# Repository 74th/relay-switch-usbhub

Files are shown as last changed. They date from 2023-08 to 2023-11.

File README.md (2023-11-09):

# Relay Switch USB 2.0 Hub

This is a USB hub with USB switching function using relays.

Many existing USB hubs with USB host switching function only allow 2-port switching, and I made this kit because we wanted a 4-port hub.
Since there are no USB hubs using USB Type-C available on the market, it is convenient to use USB Type-C.
Since I wanted to place the USB hub behind the display, we also added the ability to switch remotely using a Grove cable.

Usually a dedicated USB switching IC should be used for USB switching, but this is achieved by using a relay to switch between DM/DP. It works by me, so I am not guaranteeing that it works, but I am publishing it.

リレーを使った USB 切り替え機能付き USB ハブです。

既存の USB ホスト切り替え機能付き USB ハブでは、多くが 2 ポートしか切り替えられず、4 ポートが欲しかったため作りました。
USB Type-C を使った USB ハブは販売されていないため、USB Type-C が使えると便利です。
USB ハブはディスプレイの裏に置きたかったため、Grove ケーブルを使ってリモートから切り替えられる機能もつけました。

本来は USB 切り替えには USB 切り替え専用の IC を使うべきですが、これはリレーを使って DM/DP を切り替えることで実現しています。私の所では動作しているので、動作は保証しませんが、公開しています。

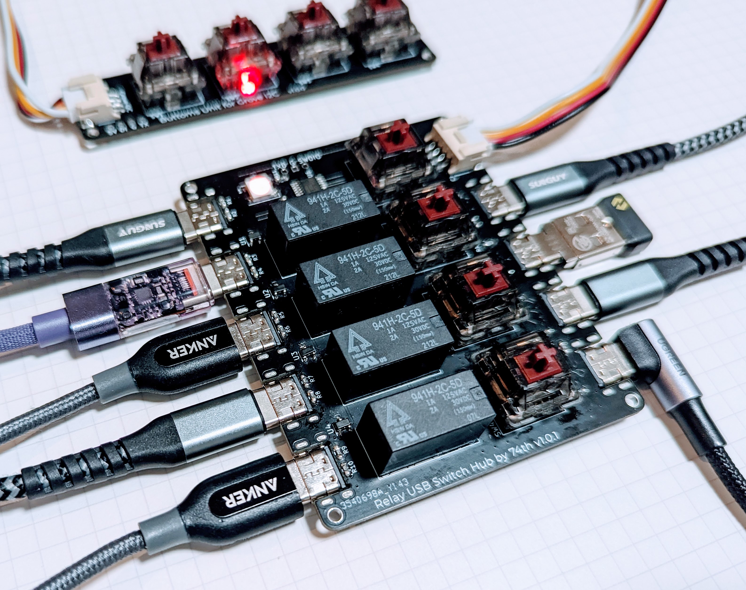
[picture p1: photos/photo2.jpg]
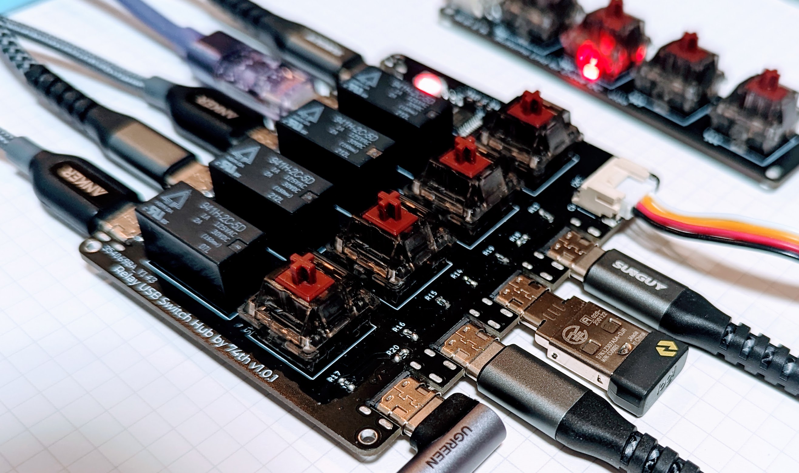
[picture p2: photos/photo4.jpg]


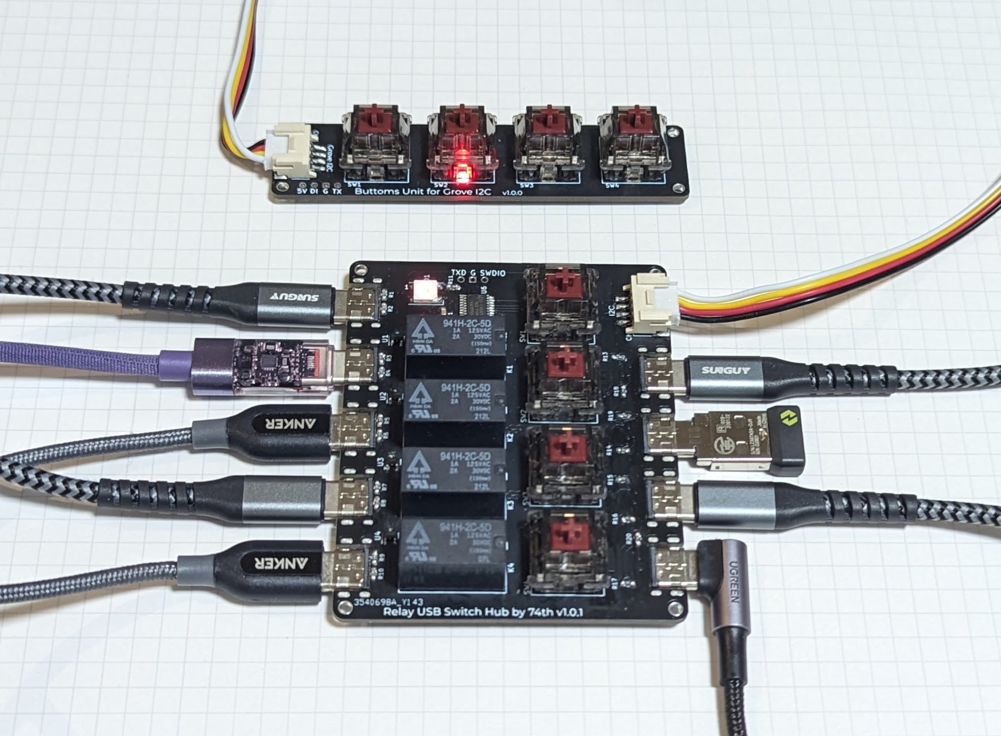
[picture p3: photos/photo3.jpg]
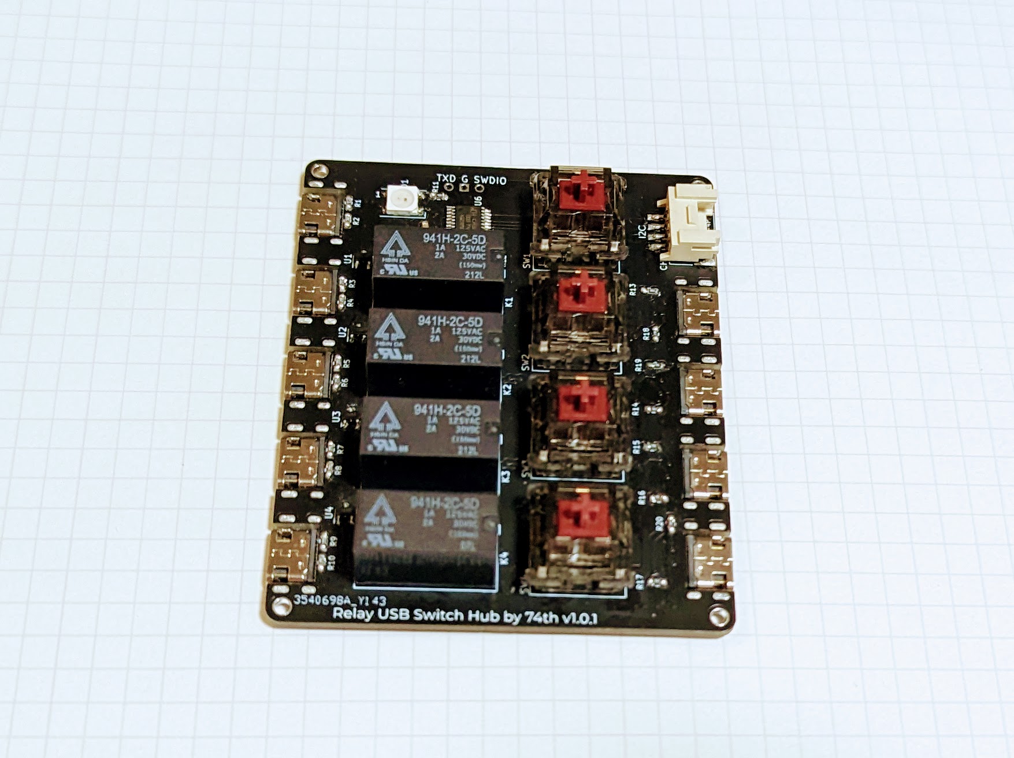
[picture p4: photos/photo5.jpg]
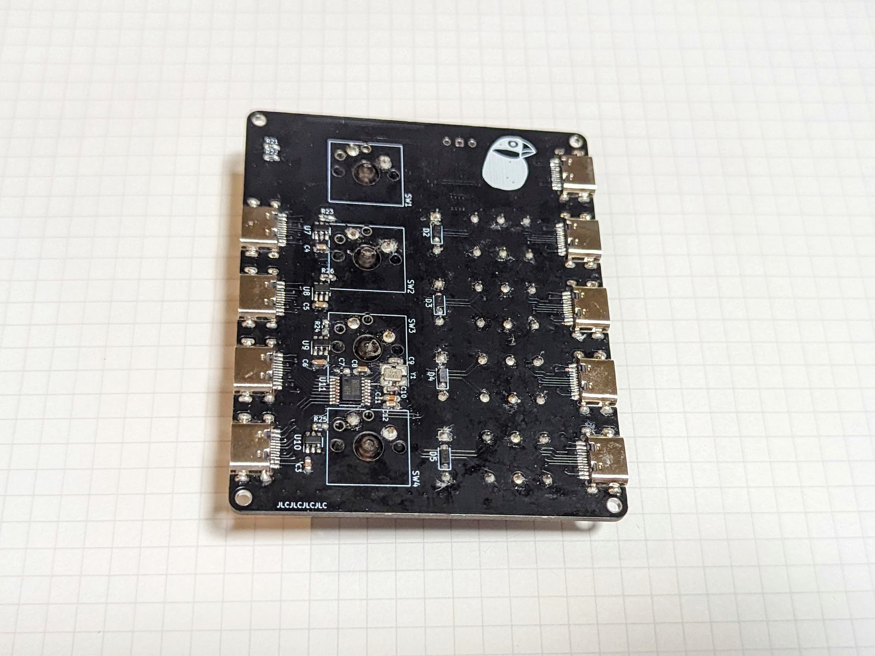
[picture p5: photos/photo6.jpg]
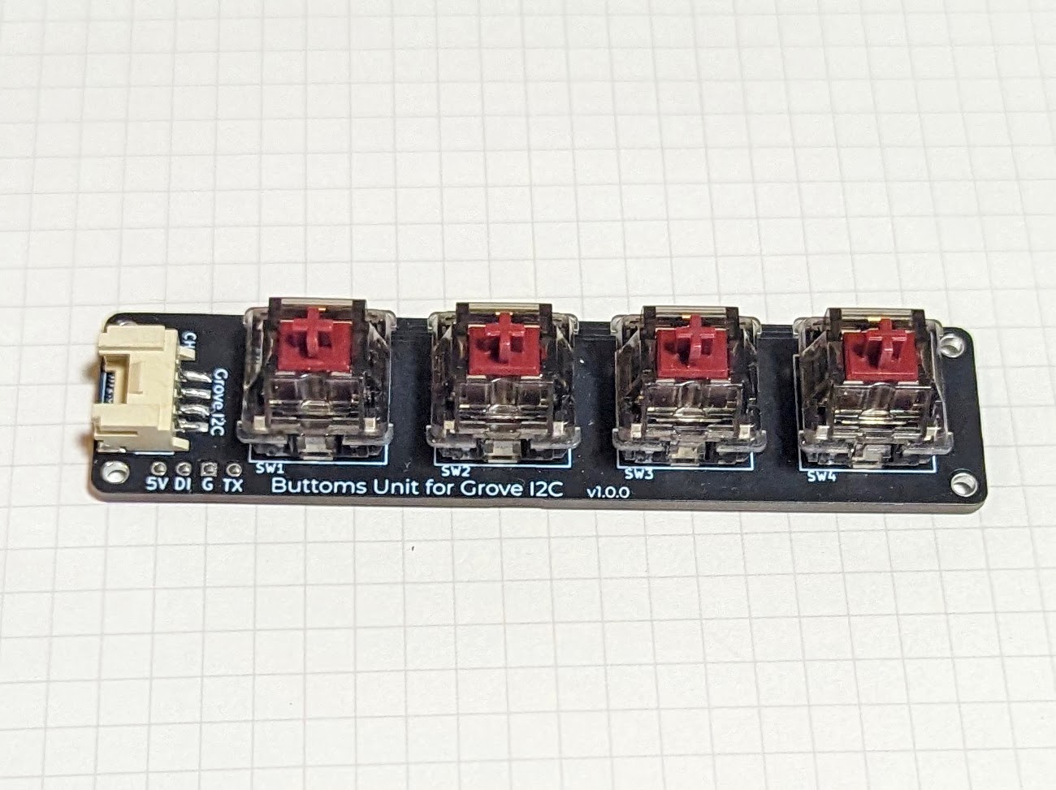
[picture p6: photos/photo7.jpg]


> Shop [BOOTH](https://74th.booth.pm/items/5080690)

## features

- Switch between 4 USB Hosts with Relay
- 4-port USB 2.0 hub using CH334
- MX compatible DIY keyboard switches can be used to switch between USB hosts
- Currently enabled USB host is indicated by LED color
- A Grove cable can be used to place a USB host switching switch at a remote location
- Power protection IC on both USB device and USB host side
- USB port next to LED for power supply
- All USB ports are Type-C

### Japanese

- リレーを使った USB ホスト切り替え機能
- CH334 を使った 4 ポート USB 2.0 ハブ
- USB ホストの切り替えスイッチには MX 互換自作キーボードスイッチが使える
- 現在有効な USB ホストを LED の色で表示する
- Grove ケーブルで、離れた位置に USB ホストを切り替えるスイッチを置くことができる
- USB デバイス、USB ホスト側の両方に電源保護 IC を搭載
- LED 横の USB ポートは電源供給用
- 全ての USB ポートは Type-C

## Repository Structure

- Relay USB Hub
  - PCB KiCad Data: [./main-pcb](./main-pcb)
  - Relay Control MCU Firmware(CH32V003F6P6): [./main-firmware](./main-firmware)
  - Case 3D Printer Model(WIP): [./case/case-bottom.stl](./case/case-bottom.stl)
- Button Unit Grove I2C
  - PCB KiCad Data: [./remote_switch-pcb](./remote_switch-pcb)
  - Button Unit MCU Firmware(CH32V003F6P6): [./remote_switch-firmware](./remote_switch-firmware)
  - Case 3D Printer Model(WIP): [./case/remote-bottom.stl](./case/remote-bottom.stl)

## About Using IC

- CH334R: USB 2.0 Hub controller IC
  - Product Site: https://www.wch-ic.com/products/CH334.html
  - Datasheet: https://www.wch-ic.com/downloads/CH334DS0_PDF.html
- CH32V003: Low Cost General Purpose MCU
  - Product Site: https://www.wch-ic.com/products/CH32V003.html
  - Datasheet: https://www.wch-ic.com/downloads/CH32V003DS0_PDF.html

## Relay USB Hub v1.0.1

- Semantics: [PDF](./main-pcb/relay_usb_switch_hub-v1.0.1-semantics.pdf) [Kicanvas](https://kicanvas.org/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)
- PCB: [Kicanvas](https://kicanvas.org/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)

### BOM

| Reference | Name | Quantity |
| --- | --- | --- |
| C1, C3-C6, C8, C12 | Capacitor 0603 10uF | 7 |
| C2, C11 | Capacitor 0603 100nF | 2 |
| C7 | NC | 1 |
| C9, C10 | Capacitor 0603 20-22pF | 2 |
| CH2 | HY2.0 Socket SMD 4Pin - I2C | 1 |
| D1 | RGBLED WS2812B | 1 |
| D2-D5 | Fast Switching Diode SOD-123 1N4148W | 4 |
| J1-J4 | USB Type-C Receptacle - USB Device | 4 |
| J5 | USB Type-C Receptacle - Power | 1 |
| J6-J9 | USB Type-C Receptacle - Com Host | 4 |
| K1-K4 | 5V 2 Form C Relay | 4 |
| R1-R10 | Register 0603 5.1kΩ | 10 |
| R11 | Register 0603 27Ω | 1 |
| R12 | Register 0603 10kΩ | 1 |
| R13-R20, R23-R26 | Register 0603 56kΩ | 12 |
| R21, R22 | Register 0603 1kΩ | 2 |
| SW1-SW4 | Cherry MX Compatible Switch or Kailh Choc Switch | 4 |
| U1-U4 | USB Power Protection IC SOT-23 CH213K | 4 |
| U6 | MCU LQFP48 WCH CH32V003F4P6 | 1 |
| U7-U10 | USB Power Protection IC SOT-23-6L CH217K | 4 |
| U11 | USB 2.0 Hub Controller QSOP-16 CH334R | 1 |
| Y1 | Crystal 3225 12MHz | 1 |

## Button Unit Grove v1.0.0

- Semantics: [PDF](./remote_switch-pcb/button_unit_grove_i2c-v1.0.0-semantics.pdf) [Kicanvas](https://kicanvas.org/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)
- PCB: [Kicanvas](https://kicanvas.org/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)

### BOM

| Reference | Name | Quantity |
| --- | --- | --- |
| C1 | Capacitor 0805 100nF | 1 |
| C2 | Capacitor 0805 10uF | 1 |
| CH1 | HY2.0 Socket SMD 4Pin - Grove I2C | 1 |
| D1-D4 | RGBLED 3528 SK6812MINI-E | 4 |
| R1 | Register 0805 10kΩ | 1 |
| R2 | Register 0805 27Ω | 1 |
| SW1-SW4 | Cherry MX Compatible Switch or Kailh Choc Switch | 4 |
| U1 | MCU LQFP48 WCH CH32V003F4P6 | 1 |

## License

MIT

日本では販売しないでいただけるとありがたいです。

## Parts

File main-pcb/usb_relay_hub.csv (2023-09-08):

Reference | Value | Footprint | Sim.Device | Sim.Pins | 数量
C1, C3-C6, C8, C12 | 10u | $74th:Capacitor_0603_1608 |  |  | 7
C2, C11 | 100n | $74th:Capacitor_0603_1608 |  |  | 2
C9, C10 | 22p | $74th:Capacitor_0603_1608 |  |  | 2
CH1 | Dubug | $74th:CH32V003-DebugPort |  |  | 1
CH2 | I2C | $74th:HY2.0_Socket_SMD_4Pin |  |  | 1
D1 | WS2812B | LED_SMD:LED_WS2812B_PLCC4_5.0x5.0mm_P3.2mm |  |  | 1
D2-D5 | 1N4148W | $74th:D_SOD-123 | D | 1=K 2=A | 4
J1-J4 | USB2.0_C_v3-R | $74th:USB-C-12-Pin-MidMount-ali-v5 |  |  | 4
J5 | Power | $74th:USB-C-12-Pin-MidMount-ali-v5 |  |  | 1
J6-J9 | Com | $74th:USB-C-12-Pin-MidMount-ali-v5 |  |  | 4
K1-K4 | 941H-2C-5D | Relay_THT:Relay_DPDT_Finder_30.22 |  |  | 4
R1-R10 | 5.1k | $74th:Register_0603_1608 |  |  | 10
R11 | 27 | $74th:Register_0603_1608 |  |  | 1
R12 | 10k | $74th:Register_0603_1608 |  |  | 1
R13-R20, R23-R26 | 56k | $74th:Register_0603_1608 |  |  | 12
R21, R22 | 1k | $74th:Register_0603_1608 |  |  | 2
SW1-SW4 | SW_Push | $sparrow62:MXChocDirect_1Side_1.0u |  |  | 4
U1-U4 | CH213K | Package_TO_SOT_SMD:SOT-23 |  |  | 4
U6 | CH32V003F4P6 | Package_SO:TSSOP-20_4.4x6.5mm_P0.65mm |  |  | 1
U7-U10 | CH217K | Package_TO_SOT_SMD:SOT-23-6 |  |  | 4
U11 | CH334R | Package_SO:QSOP-16_3.9x4.9mm_P0.635mm |  |  | 1
Y1 | 12M | $74th:Crystal_SMD_3225-4Pin_3.2x2.5mm_HandSoldering |  |  | 1

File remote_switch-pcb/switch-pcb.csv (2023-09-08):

Reference | Value | Footprint | 数量
C1 | 100n | $74th:Capacitor_0805_2012 | 1
C2 | 10u | $74th:Capacitor_0805_2012 | 1
CH1 | Grove I2C | $74th:HY2.0_Socket_SMD_4Pin | 1
CH2 | SWD 1Wire & UART TX | $74th:CH32V003-DebugPort_with_vcc | 1
D1-D4 | SK6812MINI | $74th:YS-SK6812MINI-E-BACK-RIGHT | 4
R1 | 10k | $74th:Register_0805_2012 | 1
R2 | 27 | $74th:Register_0805_2012 | 1
SW1-SW4 | SW_Push | $sparrow62:MXChocDirect_1Side_1.0u | 4
U1 | CH32V003F4P6 | Package_SO:TSSOP-20_4.4x6.5mm_P0.65mm | 1

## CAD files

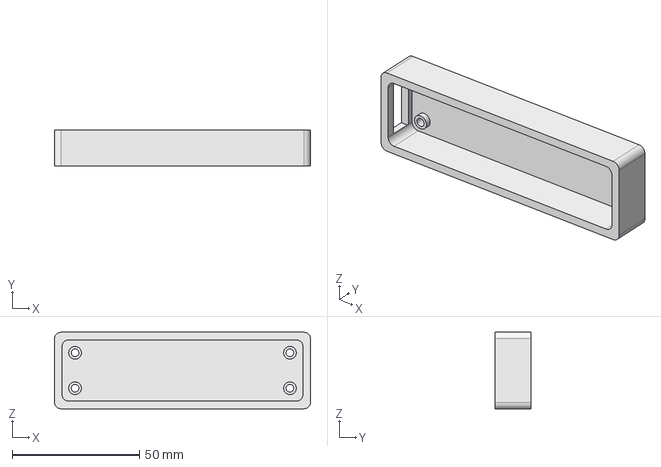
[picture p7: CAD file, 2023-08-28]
case/releay-switch-usbhub-remote.FCStd
100.6 x 14.0 x 30.1 mm

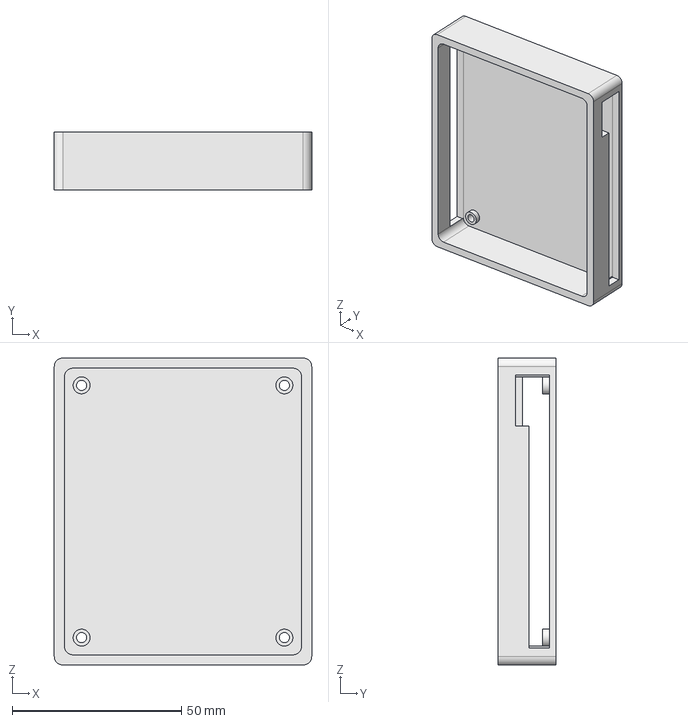
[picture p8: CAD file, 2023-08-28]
case/relay-switch-usbhub-bottom.FCStd
76.0 x 17.2 x 90.6 mm

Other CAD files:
case/remote-bottom.stl
case/case-bottom.stl

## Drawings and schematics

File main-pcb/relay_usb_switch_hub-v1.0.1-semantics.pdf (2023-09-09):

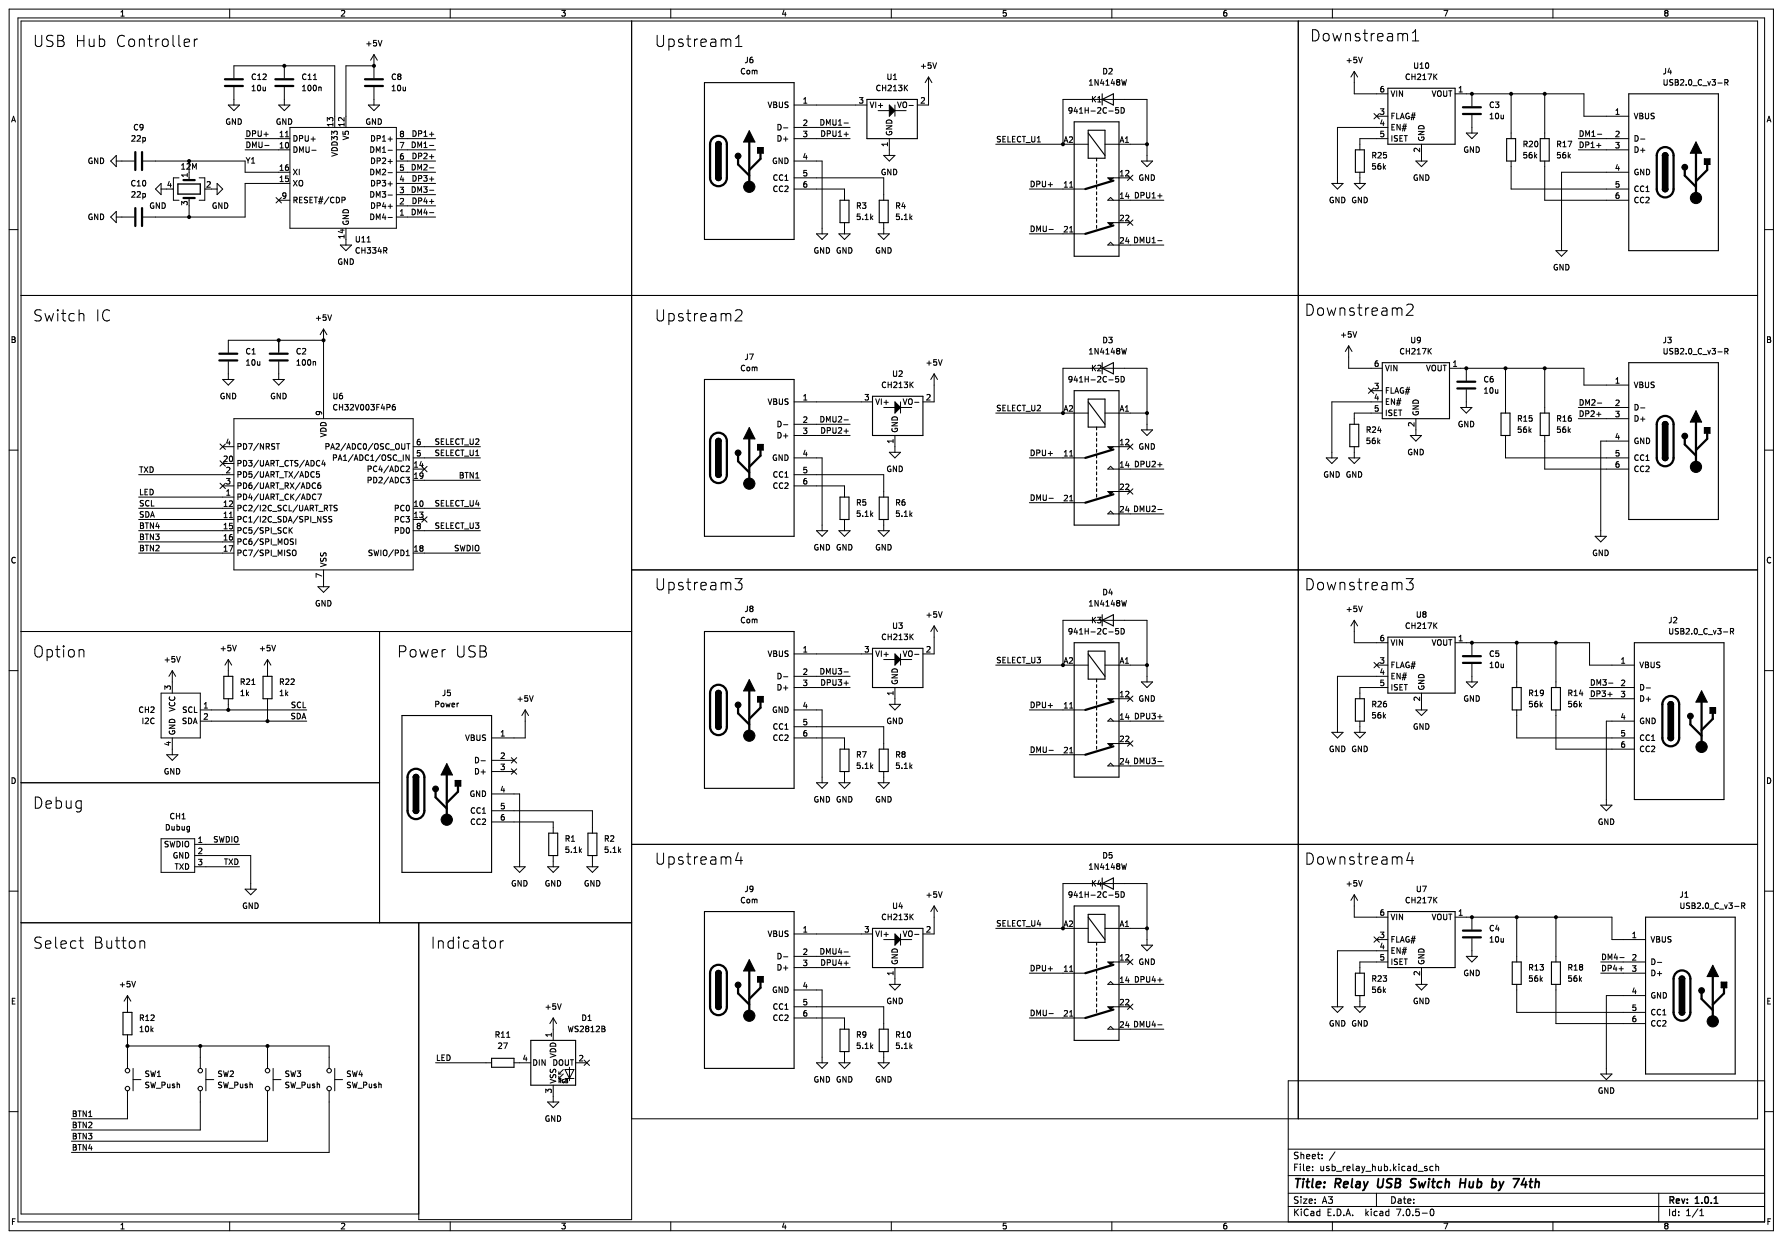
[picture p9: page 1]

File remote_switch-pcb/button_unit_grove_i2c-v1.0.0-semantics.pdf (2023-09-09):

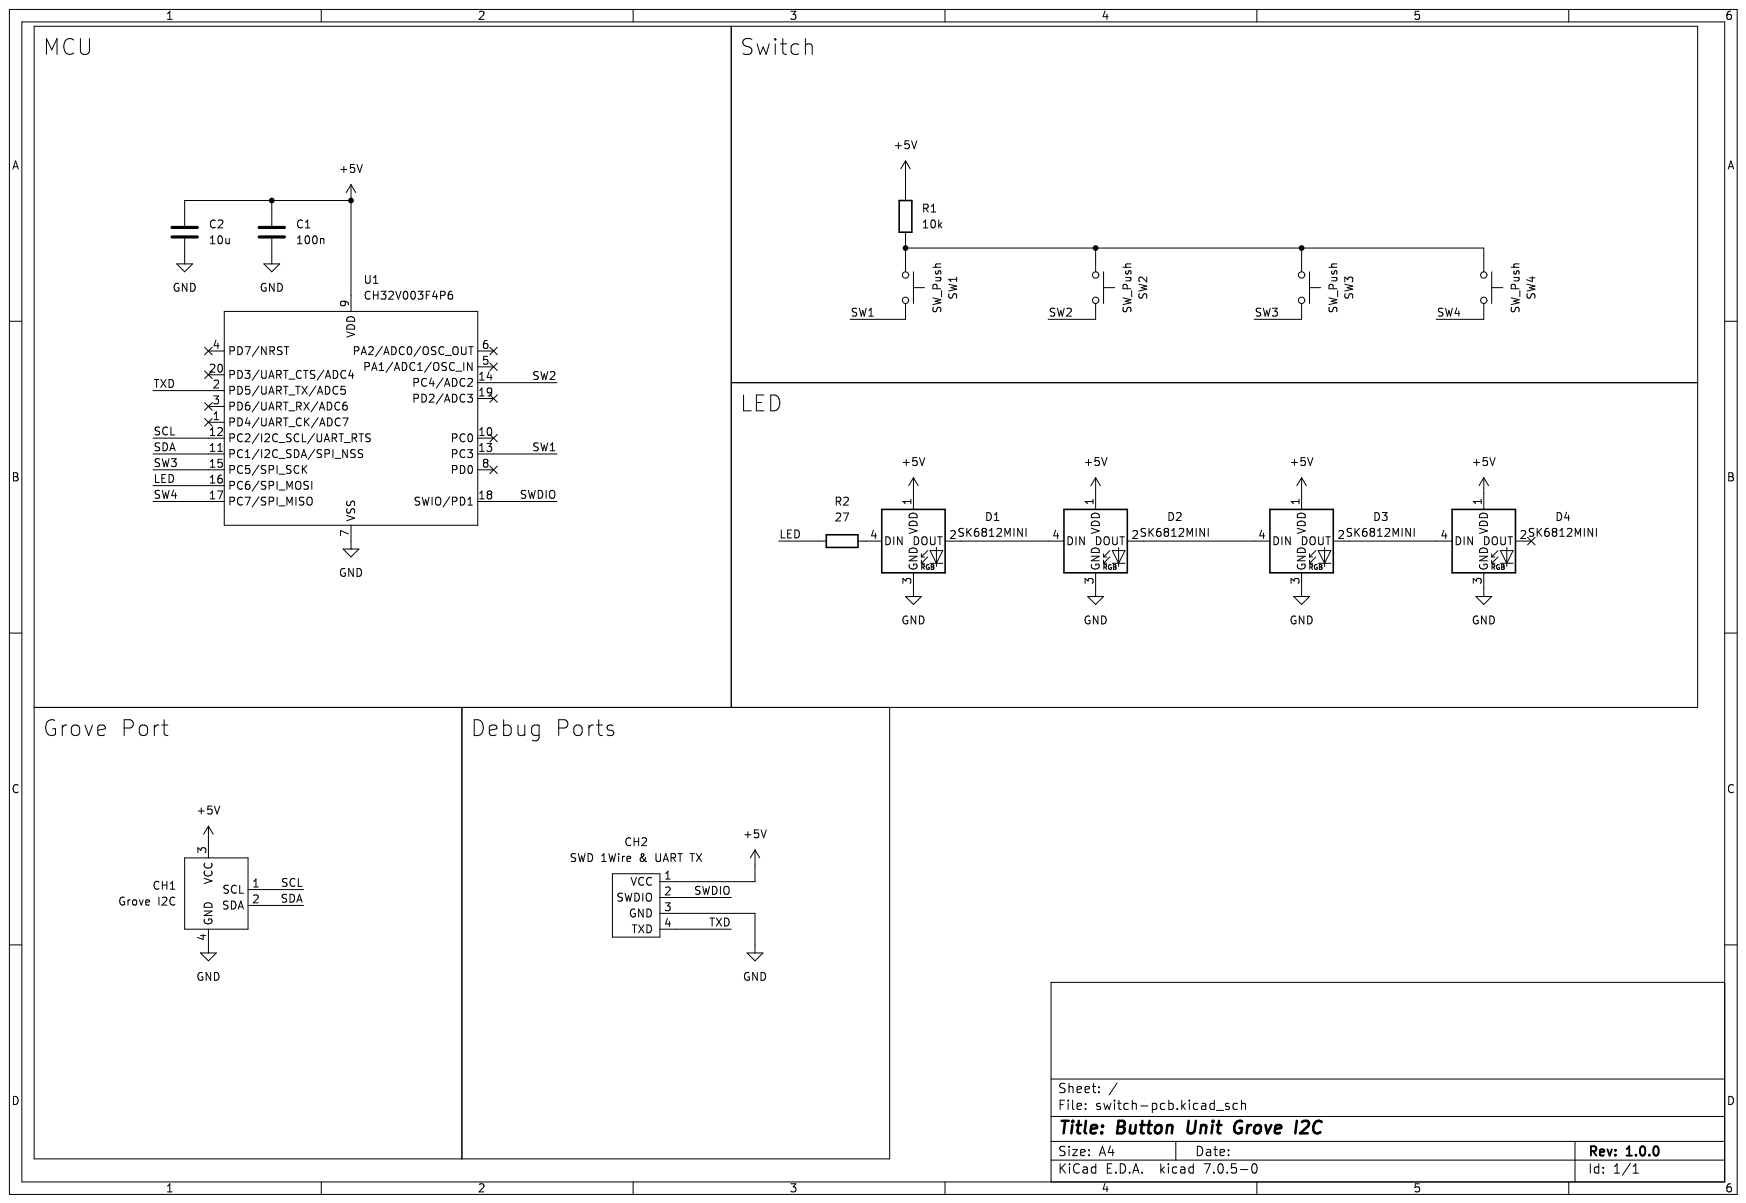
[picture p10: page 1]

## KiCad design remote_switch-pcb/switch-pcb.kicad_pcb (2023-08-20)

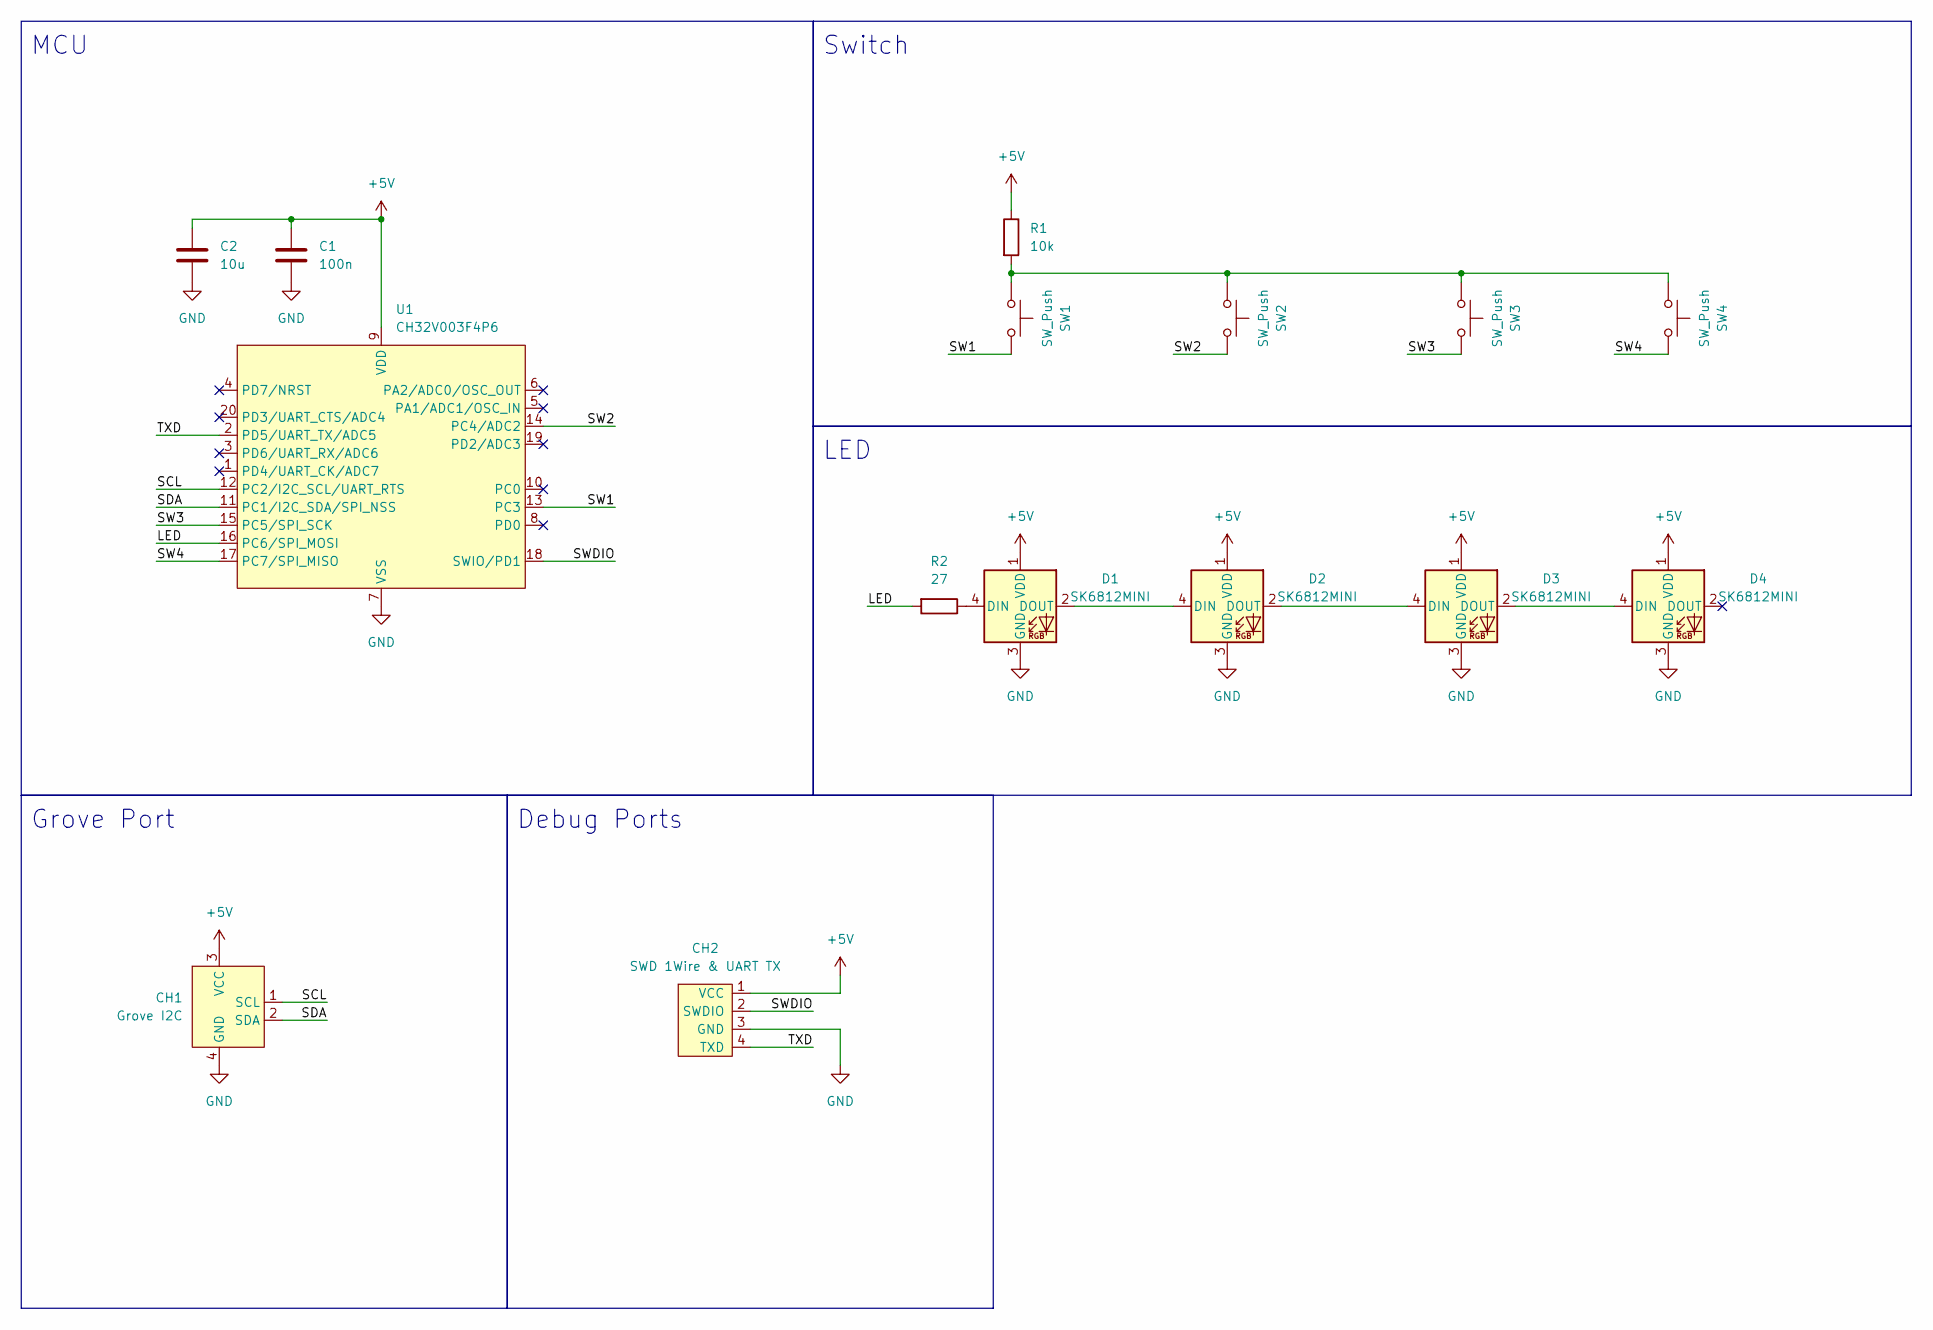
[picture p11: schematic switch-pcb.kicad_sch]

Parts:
C1: 100n; Capacitor_0805_2012
C2: 10u; Capacitor_0805_2012
CH1: Grove I2C; HY2.0_Socket_SMD_4Pin
CH2: SWD 1Wire & UART TX; CH32V003-DebugPort_with_vcc
D1, D2, D3, D4: SK6812MINI; YS-SK6812MINI-E-BACK-RIGHT
R1: 10k; Register_0805_2012
R2: 27; Register_0805_2012
SW1, SW2, SW3, SW4: SW_Push; MXChocDirect_1Side_1.0u
U1: CH32V003F4P6; TSSOP-20_4.4x6.5mm_P0.65mm

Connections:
+5V: C1.1, C2.1, CH1.3 (VCC), CH2.1 (VCC), D1.1 (VDD), D2.1 (VDD), D3.1 (VDD), D4.1 (VDD), R1.1, U1.9 (VDD)
/LED: R2.2, U1.16 (PC6/SPI_MOSI)
/SCL: CH1.1 (SCL), U1.12 (PC2/I2C_SCL/UART_RTS)
/SDA: CH1.2 (SDA), U1.11 (PC1/I2C_SDA/SPI_NSS)
/SW1: SW1.2, U1.13 (PC3)
/SW2: SW2.2, U1.14 (PC4/ADC2)
/SW3: SW3.2, U1.15 (PC5/SPI_SCK)
/SW4: SW4.2, U1.17 (PC7/SPI_MISO)
/SWDIO: CH2.2 (SWDIO), U1.18 (SWIO/PD1)
/TXD: CH2.4 (TXD), U1.2 (PD5/UART_TX/ADC5)
GND: C1.2, C2.2, CH1.4 (GND), CH2.3 (GND), D1.3 (GND), D2.3 (GND), D3.3 (GND), D4.3 (GND), U1.7 (VSS)
unnamed: D1.4 (DIN), R2.1
unnamed: D1.2 (DOUT), D2.4 (DIN)
unnamed: D2.2 (DOUT), D3.4 (DIN)
unnamed: D3.2 (DOUT), D4.4 (DIN)
unnamed: R1.2, SW1.1, SW2.1, SW3.1, SW4.1

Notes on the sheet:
LED
Debug Ports
Switch
MCU
Grove Port

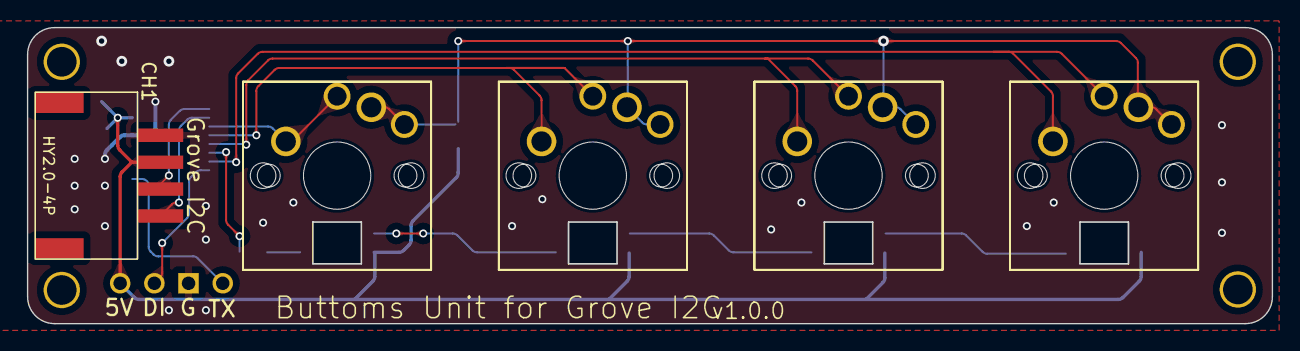
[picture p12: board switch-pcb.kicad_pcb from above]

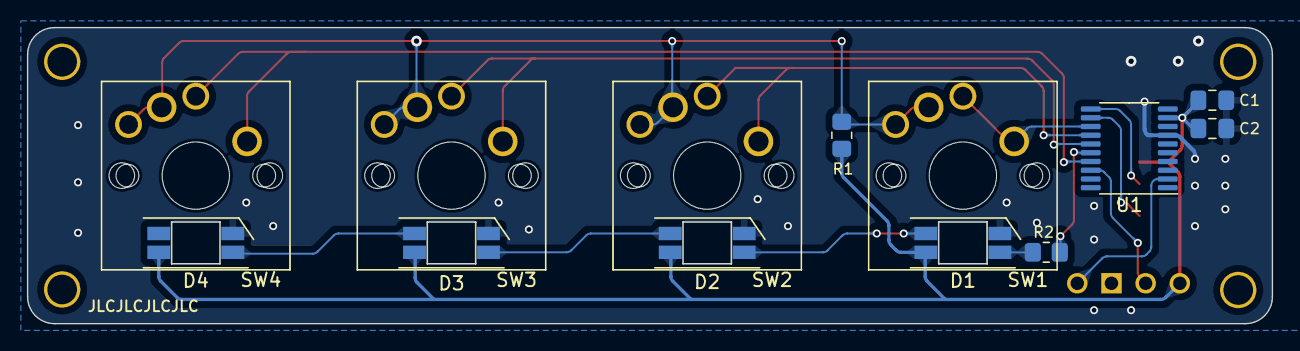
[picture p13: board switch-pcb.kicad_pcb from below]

Board: 2 copper layers, 92.5 x 22.0 mm, 19 parts (9 on the bottom side), 16 nets.

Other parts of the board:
M2-1, M2-1#2, M2-1#3, M2-1#4: M2_v2

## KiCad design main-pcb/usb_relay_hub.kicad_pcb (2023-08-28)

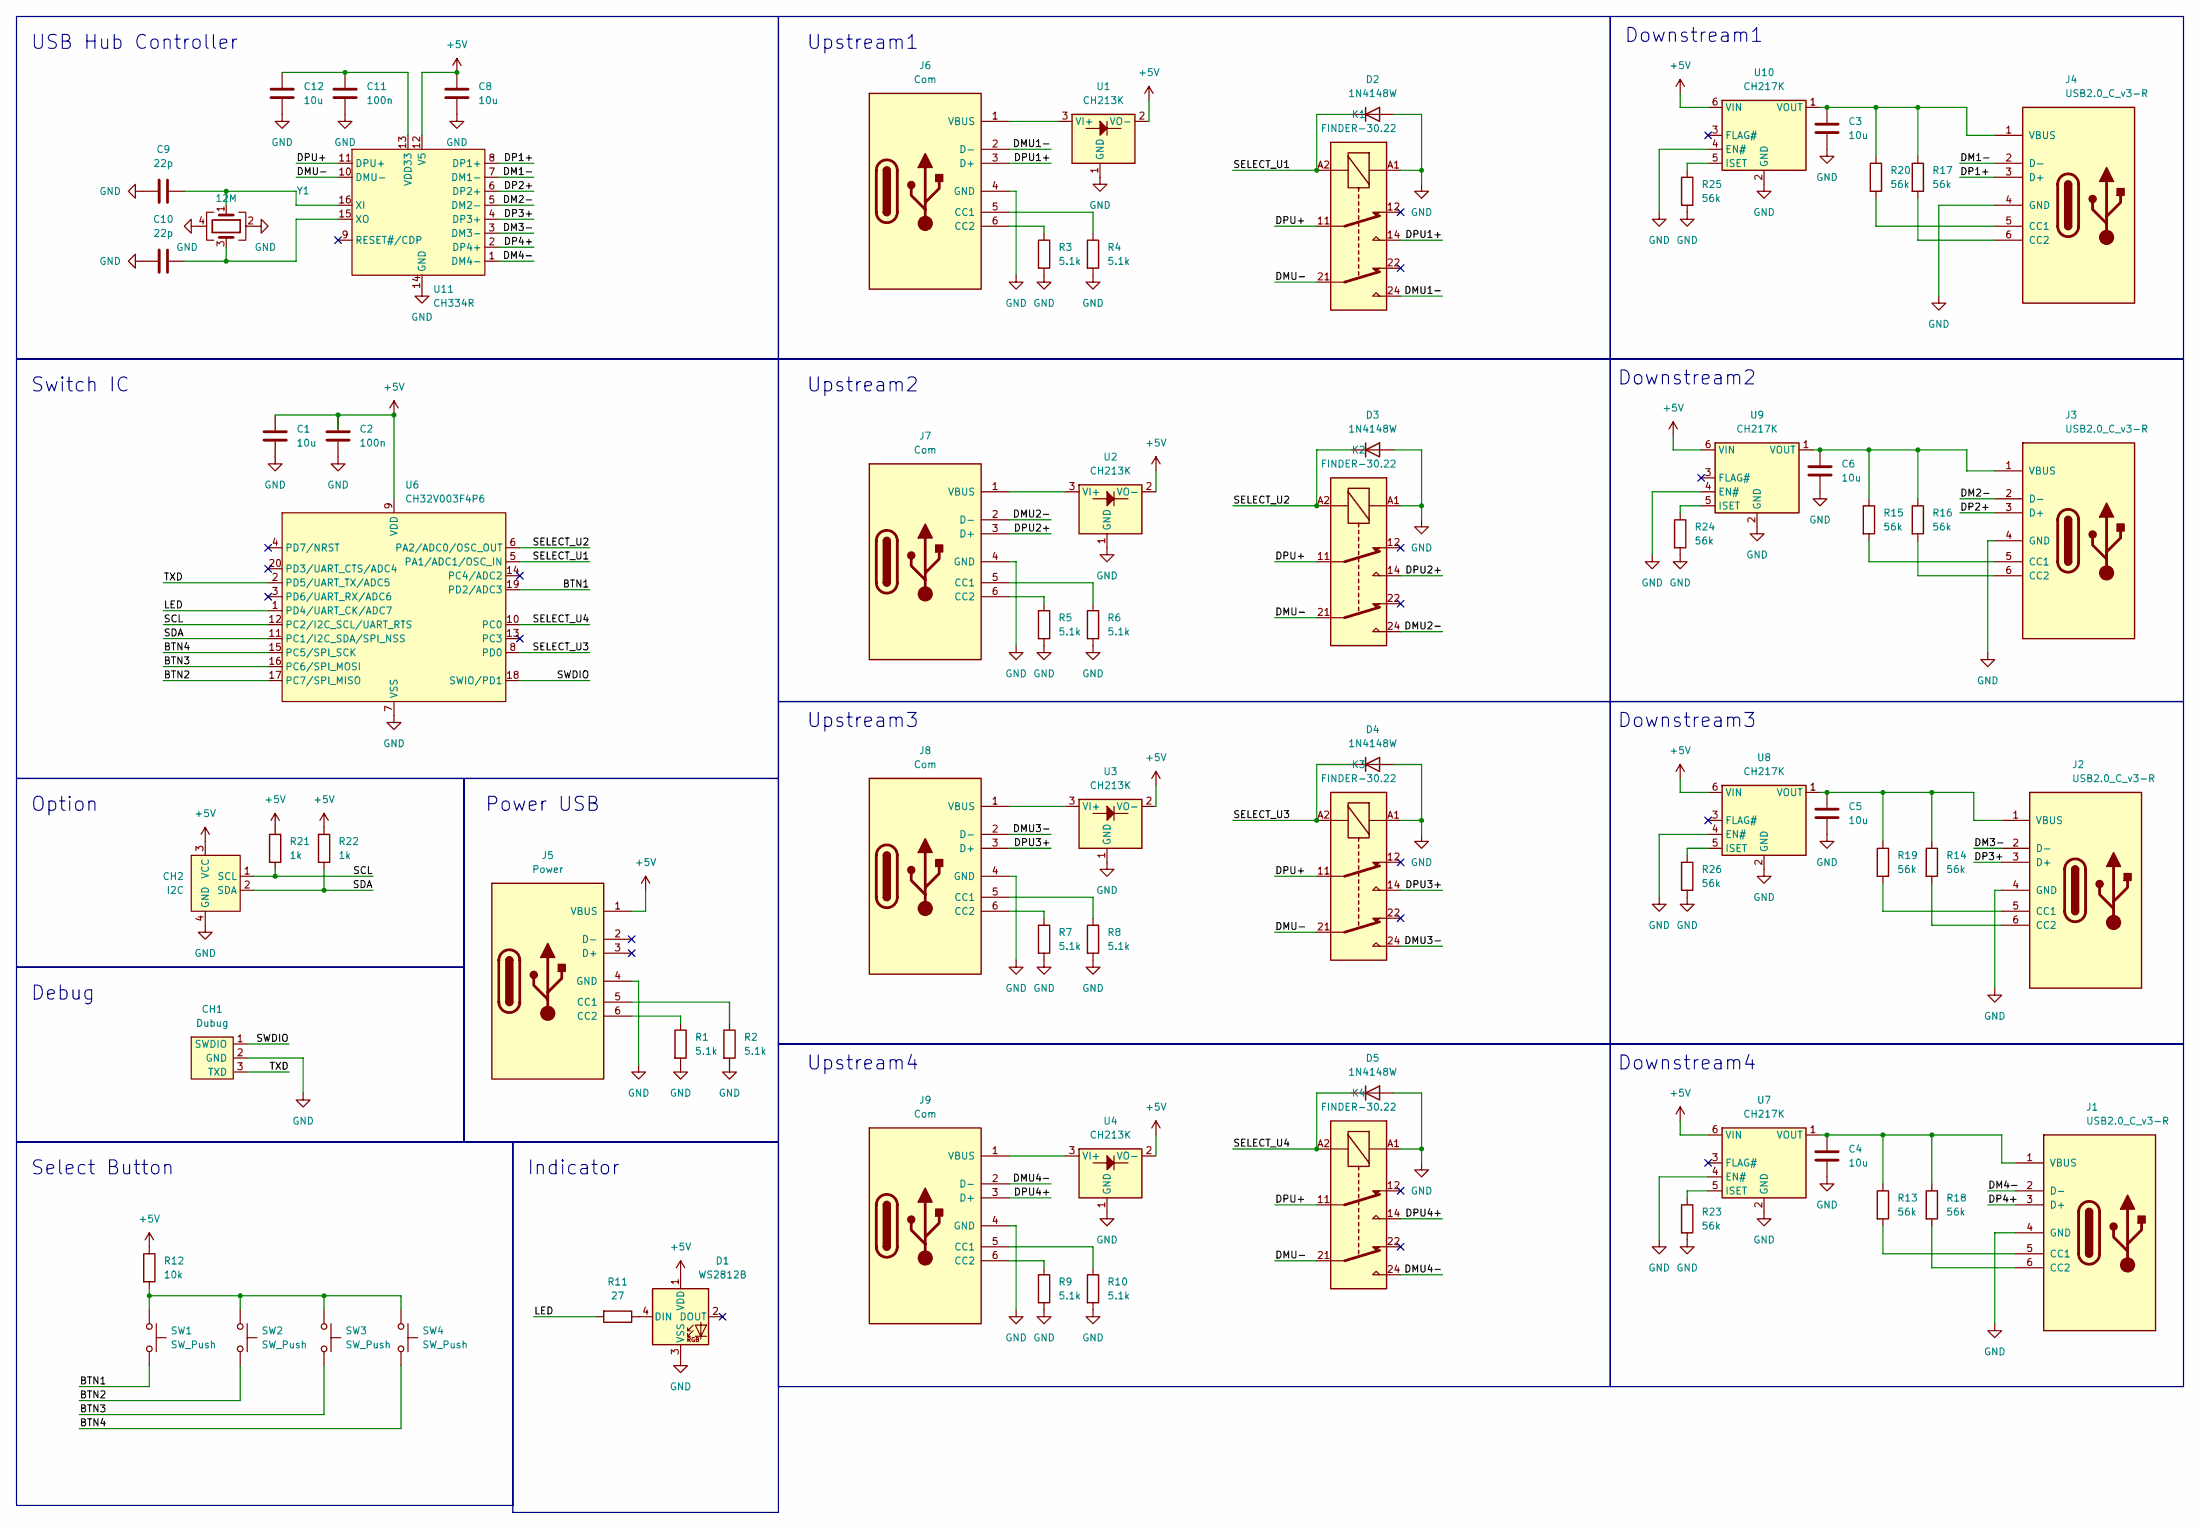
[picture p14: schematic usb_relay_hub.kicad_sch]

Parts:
C1, C3, C4, C5, C6, C8, C12: 10u; Capacitor_0603_1608
C2, C11: 100n; Capacitor_0603_1608
C9, C10: 22p; Capacitor_0603_1608
CH1: Dubug; CH32V003-DebugPort
CH2: I2C; HY2.0_Socket_SMD_4Pin
D1: WS2812B; LED_WS2812B_PLCC4_5.0x5.0mm_P3.2mm
D2, D3, D4, D5: 1N4148W; D_SOD-123
J1, J2, J3, J4: USB2.0_C_v3-R; USB-C-12-Pin-MidMount-ali-v5
J5: Power; USB-C-12-Pin-MidMount-ali-v5
J6, J7, J8, J9: Com; USB-C-12-Pin-MidMount-ali-v5
K1, K2, K3, K4: FINDER-30.22; Relay_DPDT_Finder_30.22
R1, R2, R3, R4, R5, R6, R7, R8, R9, R10: 5.1k; Register_0603_1608
R11: 27; Register_0603_1608
R12: 10k; Register_0603_1608
R13, R14, R15, R16, R17, R18, R19, R20, R23, R24, R25, R26: 56k; Register_0603_1608
R21, R22: 1k; Register_0603_1608
SW1, SW2, SW3, SW4: SW_Push; MXChocDirect_1Side_1.0u
U1, U2, U3, U4: CH213K; SOT-23
U6: CH32V003F4P6; TSSOP-20_4.4x6.5mm_P0.65mm
U7, U8, U9, U10: CH217K; SOT-23-6
U11: CH334R; QSOP-16_3.9x4.9mm_P0.635mm
Y1: 12M; Crystal_SMD_3225-4Pin_3.2x2.5mm_HandSoldering

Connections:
+5V: C1.1, C2.1, C8.1, CH2.3 (VCC), D1.1 (VDD), J5.1 (VBUS), R12.1, R21.1, R22.1, U1.2 (VO-), U2.2 (VO-), U3.2 (VO-), U4.2 (VO-), U6.9 (VDD), U7.6 (VIN), U8.6 (VIN), U9.6 (VIN), U10.6 (VIN), U11.12 (V5); also elsewhere on the board
/BTN1: SW1.2, U6.19 (PD2/ADC3)
/BTN2: SW2.2, U6.17 (PC7/SPI_MISO)
/BTN3: SW3.2, U6.16 (PC6/SPI_MOSI)
/BTN4: SW4.2, U6.15 (PC5/SPI_SCK)
/DM1-: J4.2 (D-), U11.7 (DM1-)
/DM2-: J3.2 (D-), U11.5 (DM2-)
/DM3-: J2.2 (D-), U11.3 (DM3-)
/DM4-: J1.2 (D-), U11.1 (DM4-)
/DMU1-: J6.2 (D-), K1.24
/DMU2-: J7.2 (D-), K2.24
/DMU3-: J8.2 (D-), K3.24
/DMU4-: J9.2 (D-), K4.24
/DMU-: K1.21, K2.21, K3.21, K4.21, U11.10 (DMU-)
/DP1+: J4.3 (D+), U11.8 (DP1+)
/DP2+: J3.3 (D+), U11.6 (DP2+)
/DP3+: J2.3 (D+), U11.4 (DP3+)
/DP4+: J1.3 (D+), U11.2 (DP4+)
/DPU1+: J6.3 (D+), K1.14
/DPU2+: J7.3 (D+), K2.14
/DPU3+: J8.3 (D+), K3.14
/DPU4+: J9.3 (D+), K4.14
/DPU+: K1.11, K2.11, K3.11, K4.11, U11.11 (DPU+)
/LED: R11.2, U6.1 (PD4/UART_CK/ADC7)
/SCL: CH2.1 (SCL), R21.2, U6.12 (PC2/I2C_SCL/UART_RTS)
/SDA: CH2.2 (SDA), R22.2, U6.11 (PC1/I2C_SDA/SPI_NSS)
/SELECT_U1: D2.1 (K), K1.A2, U6.5 (PA1/ADC1/OSC_IN)
/SELECT_U2: D3.1 (K), K2.A2, U6.6 (PA2/ADC0/OSC_OUT)
/SELECT_U3: D4.1 (K), K3.A2, U6.8 (PD0)
/SELECT_U4: D5.1 (K), K4.A2, U6.10 (PC0)
/SWDIO: CH1.1 (SWDIO), U6.18 (SWIO/PD1)
/TXD: CH1.3 (TXD), U6.2 (PD5/UART_TX/ADC5)
GND: C1.2, C2.2, C3.2, C4.2, C5.2, C6.2, C8.2, C9.2, C10.1, C11.2, C12.2, CH1.2 (GND), CH2.4 (GND), D1.3 (VSS), D2.2 (A), D3.2 (A), D4.2 (A), D5.2 (A), J1.4 (GND), J2.4 (GND), J3.4 (GND), J4.4 (GND), J5.4 (GND), J6.4 (GND), J7.4 (GND), J8.4 (GND), J9.4 (GND), K1.A1, K2.A1, K3.A1, K4.A1, R1.2, R2.2, R3.2, R4.2, R5.2, R6.2, R7.2, R8.2, R9.2, R10.2, R23.2, R24.2, R25.2, R26.2, U1.1 (GND), U2.1 (GND), U3.1 (GND), U4.1 (GND), U6.7 (VSS), U7.2 (GND), U7.4 (EN#), U8.2 (GND), U8.4 (EN#), U9.2 (GND), U9.4 (EN#), U10.2 (GND), U10.4 (EN#), U11.14 (GND), Y1.2, Y1.4; also elsewhere on the board
unnamed: D1.4 (DIN), R11.1
unnamed: J1.5 (CC1), R13.2
unnamed: J1.6 (CC2), R18.2
unnamed: C4.1, J1.1 (VBUS), R13.1, R18.1, U7.1 (VOUT)
unnamed: J2.5 (CC1), R19.2
unnamed: J2.6 (CC2), R14.2
unnamed: C5.1, J2.1 (VBUS), R14.1, R19.1, U8.1 (VOUT)
unnamed: J3.5 (CC1), R15.2
unnamed: J3.6 (CC2), R16.2
unnamed: C6.1, J3.1 (VBUS), R15.1, R16.1, U9.1 (VOUT)
unnamed: J4.5 (CC1), R20.2
unnamed: J4.6 (CC2), R17.2
unnamed: C3.1, J4.1 (VBUS), R17.1, R20.1, U10.1 (VOUT)
unnamed: J5.5 (CC1), R2.1
unnamed: J5.6 (CC2), R1.1
unnamed: J6.5 (CC1), R4.1
unnamed: J6.6 (CC2), R3.1
unnamed: J6.1 (VBUS), U1.3 (VI+)
unnamed: J7.5 (CC1), R6.1
unnamed: J7.6 (CC2), R5.1
unnamed: J7.1 (VBUS), U2.3 (VI+)
unnamed: J8.5 (CC1), R8.1
unnamed: J8.6 (CC2), R7.1
unnamed: J8.1 (VBUS), U3.3 (VI+)
unnamed: J9.5 (CC1), R10.1
unnamed: J9.6 (CC2), R9.1
unnamed: J9.1 (VBUS), U4.3 (VI+)
unnamed: R12.2, SW1.1, SW2.1, SW3.1, SW4.1
unnamed: R23.1, U7.5 (ISET)
unnamed: R26.1, U8.5 (ISET)
unnamed: R24.1, U9.5 (ISET)
unnamed: R25.1, U10.5 (ISET)
unnamed: C11.1, C12.1, U11.13 (VDD33)
unnamed: C9.1, U11.16 (XI), Y1.1
unnamed: C10.2, U11.15 (XO), Y1.3

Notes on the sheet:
Switch IC
Debug
Upstream2
Downstream1
Select Button
Power USB
Upstream1
Upstream4
Indicator
Downstream3
USB Hub Controller
Downstream4
Option
Downstream2
Upstream3

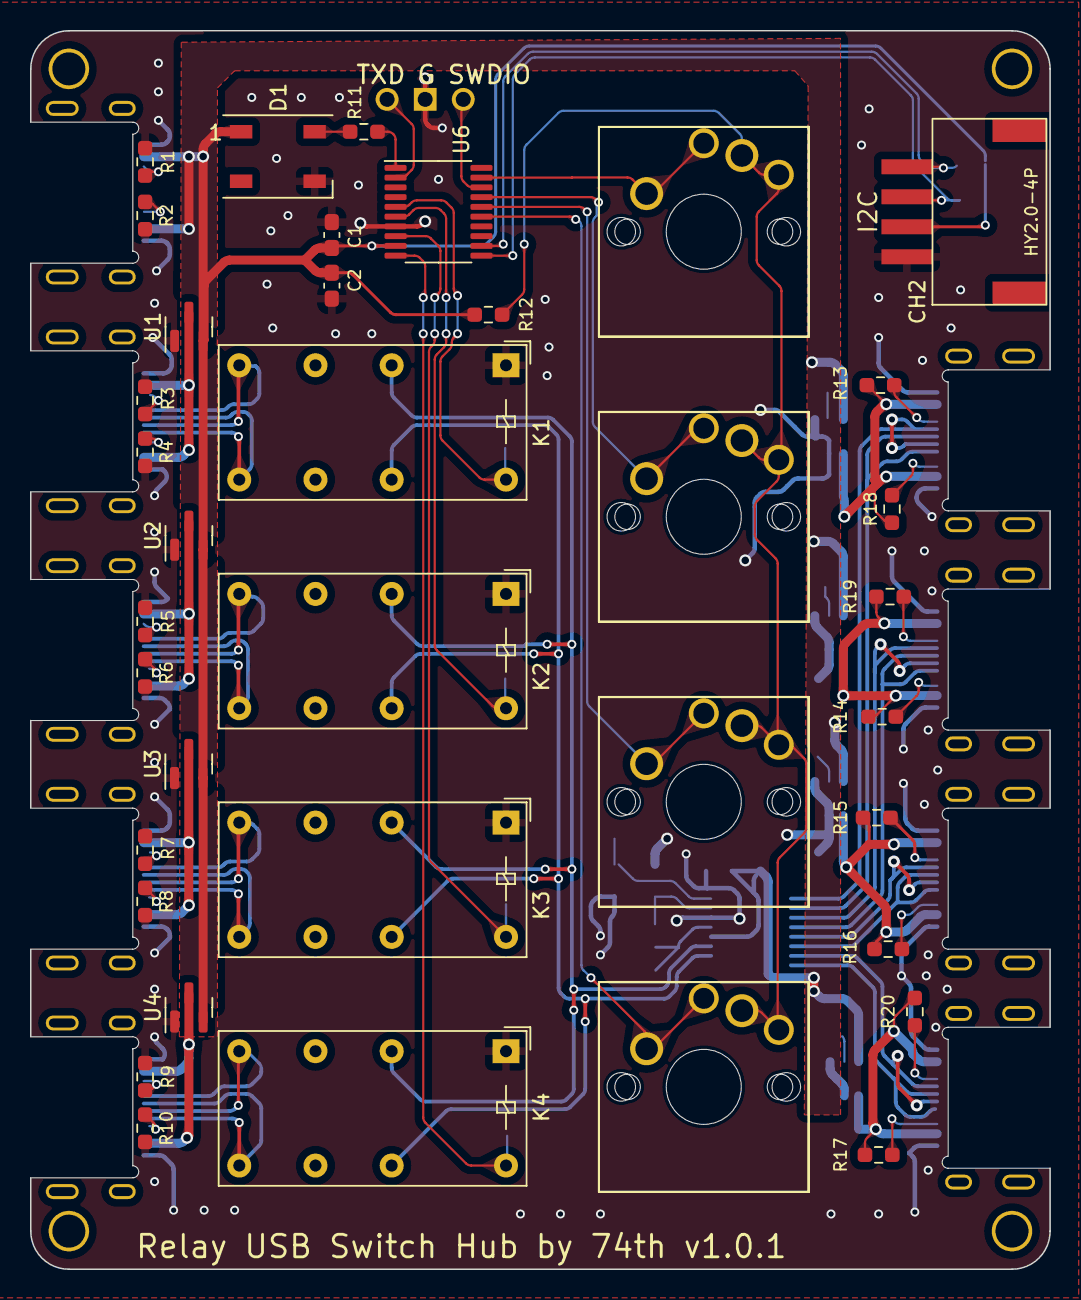
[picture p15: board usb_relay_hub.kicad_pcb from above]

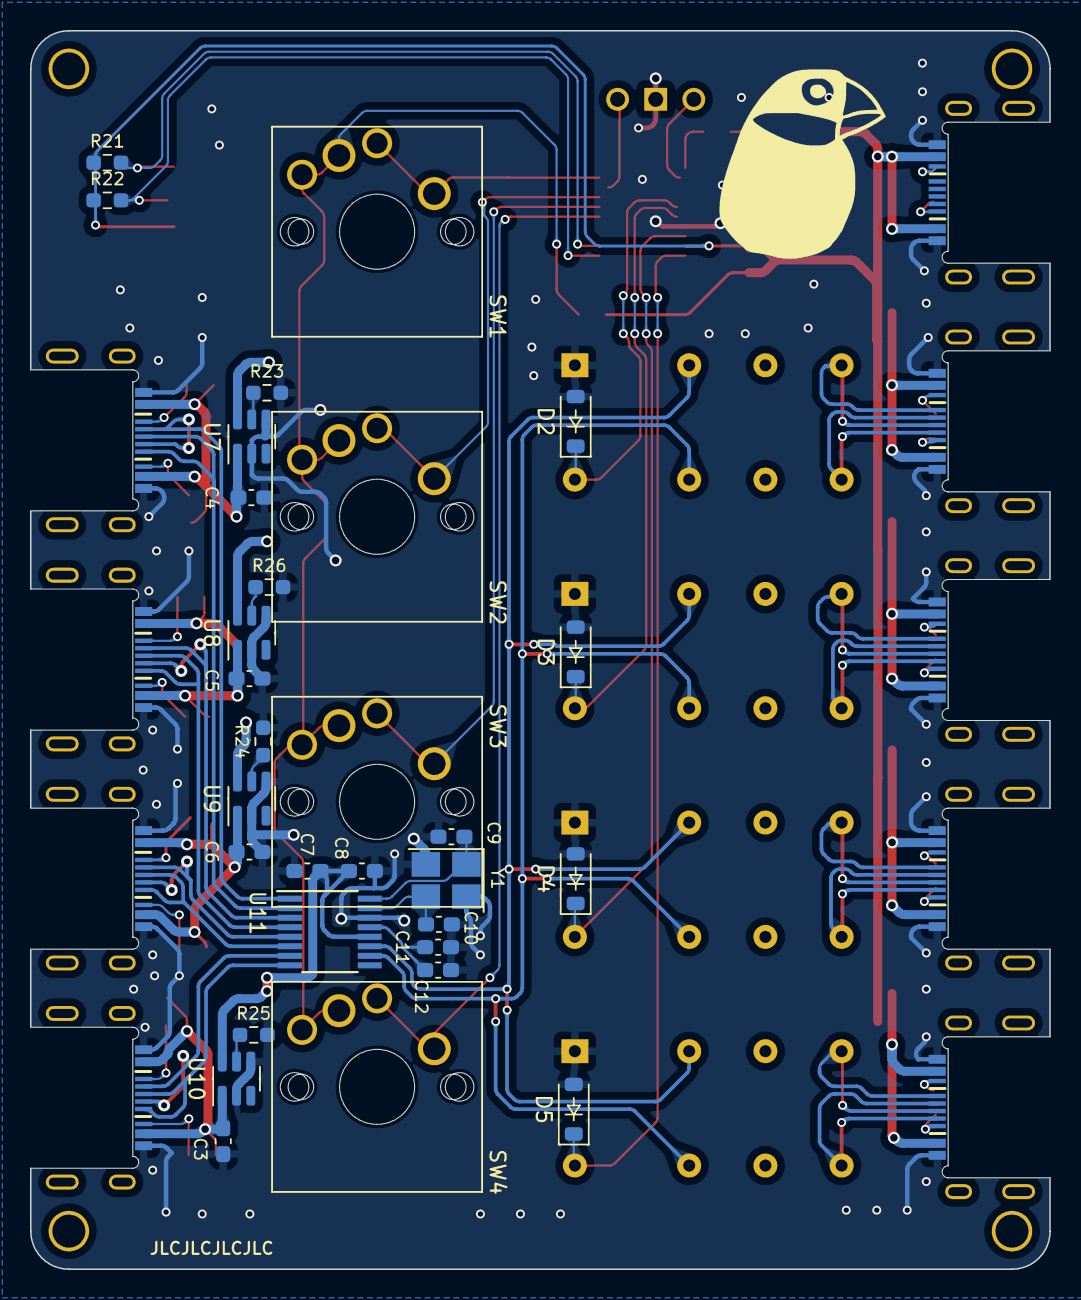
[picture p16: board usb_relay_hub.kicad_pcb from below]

Board: 2 copper layers, 67.9 x 82.5 mm, 77 parts (35 on the bottom side), 68 nets.

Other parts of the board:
C7: 100n; Capacitor_0603_1608
M1, M2, M3, M4: M2_v2

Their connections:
+5V: C7.1; also elsewhere on the board
GND: C7.2; also elsewhere on the board

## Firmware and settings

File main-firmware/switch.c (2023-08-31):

#include <stdio.h>
#include <string.h>
#include "ch32v003fun.h"
#include "ch32v003_GPIO_branchless.h"
#include "gpio_neopixel.h"
#include "switch.h"
#include "i2c_master.h"

#define I2C_ADDRESS_REMOTE_SWITCH 0x74
#define LOOP_MS 10
// #define LOOP_MS 500
#define LED_PIN GPIOv_from_PORT_PIN(GPIO_port_D, 4)
#define SELECT_U1_PIN GPIOv_from_PORT_PIN(GPIO_port_A, 1)
#define SELECT_U2_PIN GPIOv_from_PORT_PIN(GPIO_port_A, 2)
#define SELECT_U3_PIN GPIOv_from_PORT_PIN(GPIO_port_D, 0)
#define SELECT_U4_PIN GPIOv_from_PORT_PIN(GPIO_port_C, 0)
#define BTN1_PIN GPIOv_from_PORT_PIN(GPIO_port_D, 2)
#define BTN2_PIN GPIOv_from_PORT_PIN(GPIO_port_C, 7)
#define BTN3_PIN GPIOv_from_PORT_PIN(GPIO_port_C, 6)
#define BTN4_PIN GPIOv_from_PORT_PIN(GPIO_port_C, 5)

void I2C1_EV_IRQHandler(void) __attribute__((interrupt));
void I2C1_ER_IRQHandler(void) __attribute__((interrupt));

void init_rcc(void)
{
    RCC->APB2PCENR |= RCC_APB2Periph_GPIOA | RCC_APB2Periph_GPIOC | RCC_APB2Periph_GPIOD;
    RCC->APB1PCENR |= RCC_APB1Periph_I2C1;
}

void init_gpio()
{
    GPIO_port_enable(GPIO_port_A);
    GPIO_port_enable(GPIO_port_C);
    GPIO_port_enable(GPIO_port_D);
    GPIO_pinMode(LED_PIN, GPIO_pinMode_O_pushPull, GPIO_Speed_10MHz);
    GPIO_pinMode(SELECT_U1_PIN, GPIO_pinMode_O_pushPull, GPIO_Speed_10MHz);
    GPIO_pinMode(SELECT_U2_PIN, GPIO_pinMode_O_pushPull, GPIO_Speed_10MHz);
    GPIO_pinMode(SELECT_U3_PIN, GPIO_pinMode_O_pushPull, GPIO_Speed_10MHz);
    GPIO_pinMode(SELECT_U4_PIN, GPIO_pinMode_O_pushPull, GPIO_Speed_10MHz);
    GPIO_pinMode(BTN1_PIN, GPIO_pinMode_I_pullDown, GPIO_Speed_10MHz);
    GPIO_pinMode(BTN2_PIN, GPIO_pinMode_I_pullDown, GPIO_Speed_10MHz);
    GPIO_pinMode(BTN3_PIN, GPIO_pinMode_I_pullDown, GPIO_Speed_10MHz);
    GPIO_pinMode(BTN4_PIN, GPIO_pinMode_I_pullDown, GPIO_Speed_10MHz);

    GPIO_digitalWrite_0(LED_PIN);
}

uint8_t usb1_color[3] = {0x00, 0x00, 0xF0};
uint8_t usb2_color[3] = {0x00, 0xF0, 0x00};
uint8_t usb3_color[3] = {0xF0, 0x00, 0x00};
uint8_t usb4_color[3] = {0x00, 0xF0, 0xF0};

void select_usb(int no)
{
    switch (no)
    {
    case 1:
        GPIO_digitalWrite(SELECT_U1_PIN, high);
        GPIO_digitalWrite(SELECT_U2_PIN, low);
        GPIO_digitalWrite(SELECT_U3_PIN, low);
        GPIO_digitalWrite(SELECT_U4_PIN, low);
        neopixel_write(GPIOD, GPIO_Pin_4, &usb1_color, 3);
        break;
    case 2:
        GPIO_digitalWrite(SELECT_U1_PIN, low);
        GPIO_digitalWrite(SELECT_U2_PIN, high);
        GPIO_digitalWrite(SELECT_U3_PIN, low);
        GPIO_digitalWrite(SELECT_U4_PIN, low);
        neopixel_write(GPIOD, GPIO_Pin_4, &usb2_color, 3);
        break;
    case 3:
        GPIO_digitalWrite(SELECT_U1_PIN, low);
        GPIO_digitalWrite(SELECT_U2_PIN, low);
        GPIO_digitalWrite(SELECT_U3_PIN, high);
        GPIO_digitalWrite(SELECT_U4_PIN, low);
        neopixel_write(GPIOD, GPIO_Pin_4, &usb3_color, 3);
        break;
    case 4:
        GPIO_digitalWrite(SELECT_U1_PIN, low);
        GPIO_digitalWrite(SELECT_U2_PIN, low);
        GPIO_digitalWrite(SELECT_U3_PIN, low);
        GPIO_digitalWrite(SELECT_U4_PIN, high);
        neopixel_write(GPIOD, GPIO_Pin_4, &usb4_color, 3);
        break;
    }
}

int read_pushed()
{
    int pushed = 0;
    if (GPIO_digitalRead(BTN1_PIN) == high)
    {
        pushed = 1;
    }
    if (GPIO_digitalRead(BTN2_PIN) == high)
    {
        pushed = 2;
    }
    if (GPIO_digitalRead(BTN3_PIN) == high)
    {
        pushed = 3;
    }
    if (GPIO_digitalRead(BTN4_PIN) == high)
    {
        pushed = 4;
    }

    return pushed;
}

int read_remote_pushed()
{
    uint8_t data[1];
    if (i2c_receive(I2C_ADDRESS_REMOTE_SWITCH, data, 1) != 0)
    {
        return 0;
    }
    uint8_t switch_state = data[0];
    for (int i = 0; i < 4; i++)
    {
        if (switch_state & (1 << i))
        {
            return i + 1;
        }
    }
    return 0;
}

void flash_remote_usb(int no)
{
    uint8_t data[4 * 3];
    for (int i = 0; i < 4 * 3; i++)
    {
        data[i] = 0x00;
    }
    switch (no)
    {
    case 1:
        memcpy(&data[3 * 0], usb1_color, 3);
        break;
    case 2:
        memcpy(&data[3 * 1], usb2_color, 3);
        break;
    case 3:
        memcpy(&data[3 * 2], usb3_color, 3);
        break;
    case 4:
        memcpy(&data[3 * 3], usb4_color, 3);
        break;
    }
    i2c_send(I2C_ADDRESS_REMOTE_SWITCH, &data, 4 * 3);
}

int main()
{
    SystemInit();
    init_rcc();

    printf("initialize\r\n");

    init_gpio();
    init_i2c_master();

    int current_usb_no = 1;
    select_usb(1);

    printf("initialize done\r\n");

    Delay_Ms(100);

    printf("neopixel test start\r\n");

    select_usb(1);
    if (i2c_slave_available(I2C_ADDRESS_REMOTE_SWITCH))
    {
        flash_remote_usb(1);
    }

    printf("neopixel test done\r\n");

    while (1)
    {
        int remote_available = i2c_slave_available(I2C_ADDRESS_REMOTE_SWITCH);

        int pushed_no = read_pushed();
        if (remote_available)
        {
            int remote_pushed_no = read_remote_pushed();
            if (remote_pushed_no > 0)
            {
                pushed_no = remote_pushed_no;
            }
        }

        if (pushed_no > 0)
        {
            if (current_usb_no != pushed_no)
            {
                printf("pushed: %d\r\n", pushed_no);

                select_usb(pushed_no);
                if (remote_available)
                {
                    flash_remote_usb(pushed_no);
                }

                current_usb_no = pushed_no;
            }
        }

        Delay_Ms(LOOP_MS);
    }
}

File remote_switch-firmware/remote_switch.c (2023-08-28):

#include "ch32v003fun.h"
#include "ch32v003_GPIO_branchless.h"
#include "gpio_neopixel.h"
#include "remote_switch.h"
#include <stdio.h>
#include <stdbool.h>

#define I2C_SLAVE_ADDRESS 0x74
#define LOOP_MS 10
#define LED_NUM 4
#define LED_BUF_LEN 3 * LED_NUM
#define LED_PIN GPIOv_from_PORT_PIN(GPIO_port_C, 6)
#define BTN1_PIN GPIOv_from_PORT_PIN(GPIO_port_C, 3)
#define BTN2_PIN GPIOv_from_PORT_PIN(GPIO_port_C, 4)
#define BTN3_PIN GPIOv_from_PORT_PIN(GPIO_port_C, 5)
#define BTN4_PIN GPIOv_from_PORT_PIN(GPIO_port_C, 7)

void I2C1_EV_IRQHandler(void) __attribute__((interrupt));
void I2C1_ER_IRQHandler(void) __attribute__((interrupt));

void init_rcc(void)
{
    RCC->APB2PCENR |= RCC_APB2Periph_GPIOA | RCC_APB2Periph_GPIOC | RCC_APB2Periph_GPIOD;
    RCC->APB1PCENR |= RCC_APB1Periph_I2C1;
}

void init_i2c_slave(uint8_t address)
{
    // https://github.com/cnlohr/ch32v003fun/blob/master/examples/i2c_slave/i2c_slave.h

    // PC1 is SDA, 10MHz Output, alt func, open-drain
    GPIOC->CFGLR &= ~(0xf << (4 * 1));
    GPIOC->CFGLR |= (GPIO_Speed_10MHz | GPIO_CNF_OUT_OD_AF) << (4 * 1);

    // PC2 is SCL, 10MHz Output, alt func, open-drain
    GPIOC->CFGLR &= ~(0xf << (4 * 2));
    GPIOC->CFGLR |= (GPIO_Speed_10MHz | GPIO_CNF_OUT_OD_AF) << (4 * 2);

    // Reset I2C1 to init all regs
    RCC->APB1PRSTR |= RCC_APB1Periph_I2C1;
    RCC->APB1PRSTR &= ~RCC_APB1Periph_I2C1;

    I2C1->CTLR1 |= I2C_CTLR1_SWRST;
    I2C1->CTLR1 &= ~I2C_CTLR1_SWRST;

    // Set module clock frequency
    uint32_t prerate = 2000000; // I2C Logic clock rate, must be higher than the bus clock rate
    I2C1->CTLR2 |= (APB_CLOCK / prerate) & I2C_CTLR2_FREQ;

    // Enable interrupts
    I2C1->CTLR2 |= I2C_CTLR2_ITBUFEN;
    I2C1->CTLR2 |= I2C_CTLR2_ITEVTEN; // Event interrupt
    I2C1->CTLR2 |= I2C_CTLR2_ITERREN; // Error interrupt

    NVIC_EnableIRQ(I2C1_EV_IRQn); // Event interrupt
    NVIC_SetPriority(I2C1_EV_IRQn, 2 << 4);
    NVIC_EnableIRQ(I2C1_ER_IRQn); // Error interrupt
    // Set clock configuration
    uint32_t clockrate = 1000000;                                                    // I2C Bus clock rate, must be lower than the logic clock rate
    I2C1->CKCFGR = ((APB_CLOCK / (3 * clockrate)) & I2C_CKCFGR_CCR) | I2C_CKCFGR_FS; // Fast mode 33% duty cycle
    // I2C1->CKCFGR = ((APB_CLOCK/(25*clockrate))&I2C_CKCFGR_CCR) | I2C_CKCFGR_DUTY | I2C_CKCFGR_FS; // Fast mode 36% duty cycle
    // I2C1->CKCFGR = (APB_CLOCK/(2*clockrate))&I2C_CKCFGR_CCR; // Standard mode good to 100kHz

    // Set I2C address
    I2C1->OADDR1 = address << 1;

    // Enable I2C
    I2C1->CTLR1 |= I2C_CTLR1_PE;

    // Acknowledge the first address match event when it happens
    I2C1->CTLR1 |= I2C_CTLR1_ACK;
}

int i2c_pos = 0;
uint8_t button_state_buf = 0x00;
uint8_t led_color_buf[LED_BUF_LEN];
bool need_write_led = false;

void I2C1_EV_IRQHandler(void)
{
    uint16_t STAR1, STAR2 __attribute__((unused));
    STAR1 = I2C1->STAR1;
    STAR2 = I2C1->STAR2;

    printf("EV STAR1: 0x%04x STAR2: 0x%04x\r\n", STAR1, STAR2);

    I2C1->CTLR1 |= I2C_CTLR1_ACK;

    if (STAR1 & I2C_STAR1_ADDR) // 0x0002
    {
        printf("ADDR\r\n");
        // 最初のイベント
        // read でも write でも必ず最初に呼ばれる
        i2c_pos = 0;
    }

    if (STAR1 & I2C_STAR1_RXNE) // 0x0040
    {
        printf("RXNE write event; pos:%d \r\n", i2c_pos);
        // 1byte 受信
        if (i2c_pos < LED_BUF_LEN)
        {
            led_color_buf[i2c_pos] = I2C1->DATAR;
        }
        else
        {
            I2C1->DATAR;
        }
        i2c_pos++;
        if (i2c_pos == LED_BUF_LEN)
        {
            need_write_led = true;
            printf("ready to write led\r\n");
        }
    }

    if (STAR1 & I2C_STAR1_TXE) // 0x0080
    {
        // 1byte の read イベント（slave -> master）
        printf("TXE write event:\r\n");
        // 1byte 送信
        I2C1->DATAR = button_state_buf;
    }
}

void I2C1_ER_IRQHandler(void)
{
    uint16_t STAR1 = I2C1->STAR1;

    printf("ER STAR1: 0x%04x\r\n", STAR1);

    if (STAR1 & I2C_STAR1_BERR)           // 0x0100
    {                                     // Bus error
        I2C1->STAR1 &= ~(I2C_STAR1_BERR); // Clear error
    }

    if (STAR1 & I2C_STAR1_ARLO)           // 0x0200
    {                                     // Arbitration lost error
        I2C1->STAR1 &= ~(I2C_STAR1_ARLO); // Clear error
    }

    if (STAR1 & I2C_STAR1_AF)           // 0x0400
    {                                   // Acknowledge failure
        I2C1->STAR1 &= ~(I2C_STAR1_AF); // Clear error
    }
}

void init_gpio()
{
    GPIO_port_enable(GPIO_port_C);
    GPIO_pinMode(LED_PIN, GPIO_pinMode_O_pushPull, GPIO_Speed_10MHz);
    GPIO_pinMode(BTN1_PIN, GPIO_pinMode_I_pullDown, GPIO_Speed_10MHz);
    GPIO_pinMode(BTN2_PIN, GPIO_pinMode_I_pullDown, GPIO_Speed_10MHz);
    GPIO_pinMode(BTN3_PIN, GPIO_pinMode_I_pullDown, GPIO_Speed_10MHz);
    GPIO_pinMode(BTN4_PIN, GPIO_pinMode_I_pullDown, GPIO_Speed_10MHz);

    GPIO_digitalWrite_0(LED_PIN);
}

void read_pushed()
{
    uint8_t new = 0x00;
    new = GPIO_digitalRead(BTN1_PIN);
    new |= GPIO_digitalRead(BTN2_PIN) << 1;
    new |= GPIO_digitalRead(BTN3_PIN) << 2;
    new |= GPIO_digitalRead(BTN4_PIN) << 3;
    button_state_buf = new;
}

void write_led()
{
    printf("write led\r\n");
    neopixel_write(GPIOC, GPIO_Pin_6, &led_color_buf, LED_BUF_LEN);
}

int main()
{
    SystemInit();
    init_rcc();

    printf("initialize\r\n");

    init_i2c_slave(I2C_SLAVE_ADDRESS);
    init_gpio();

    int current_usb_no = 1;

    for (int i = 0; i < LED_BUF_LEN; i++)
        led_color_buf[i] = 0xF0;

    write_led();

    printf("initialize done\r\n");

    Delay_Ms(100);

    while (1)
    {
        read_pushed();

        if (need_write_led)
        {
            write_led();
            need_write_led = false;
        }

        Delay_Ms(LOOP_MS);
    }
}

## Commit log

2023-08-15 pcb v1.0.0
    [usb_relay_hub.kicad_pcb, usb_relay_hub.kicad_sch]
2023-08-16 update case
    [case-bottom.stl, relay-switch-usbhub-bottom.FCStd]
2023-08-27 remote switch
2023-09-09 update semantics
    [switch-pcb.kicad_sch, usb_relay_hub.kicad_sch]
